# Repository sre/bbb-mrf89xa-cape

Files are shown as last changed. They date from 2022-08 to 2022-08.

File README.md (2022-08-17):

# Beaglebone Black Cape for MRF89XA RF Chip

This is a cape for the MRF89XA RF chip using the 868 MHz ISM band.
It has an onboard antenna, which is good enough for short range
communication. Otherwise and SMA connector can be used to connect
an external amplifier/antenna.

The MRF89XA is connected to the Beaglebone SPI interface and the
relevant control lines are connected to GPIOs. Additionally the
cape has support to drive a SK6812 or WS2812 LED via SPI.

## Image

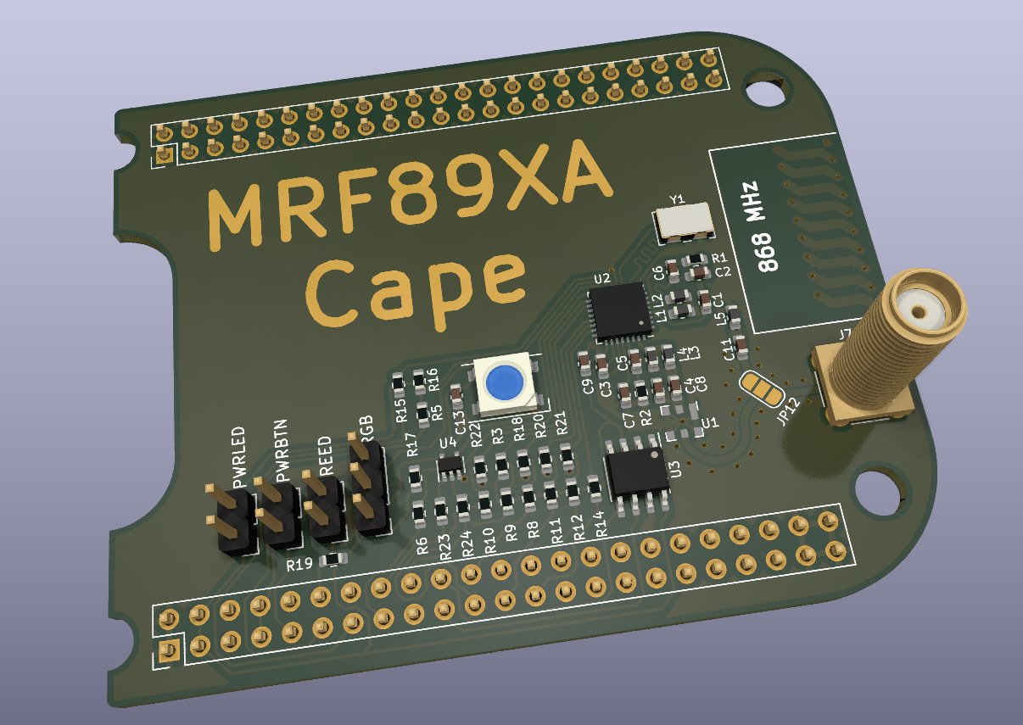
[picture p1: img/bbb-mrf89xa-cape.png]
Rendering from PCB


## Kernel

A matching devicetree overlay can be found in the dt-overlay
directory. Neither the MRF89XA nor the RGB LED currently have
an in-kernel driver. It is possible to access them via userspace
via the spidev module like this:

```
# load spidev kernel module
modprobe spidev
# tell kernel to use spidev driver for both mrf89xa interfaces
echo spidev > /sys/bus/spi/devices/spi0.0/driver_override
echo spi0.0 > /sys/bus/spi/drivers/spidev/bind
echo spidev > /sys/bus/spi/devices/spi0.1/driver_override
echo spi0.1 > /sys/bus/spi/drivers/spidev/bind
echo spidev > /sys/bus/spi/devices/spi0.2/driver_override
echo spi0.2 > /sys/bus/spi/drivers/spidev/bind

```
Afterwards the SPI devices are available as `/dev/spidev0.0`
(mrf89xa data), `/dev/spidev0.1` (mrf89xa cfg) and `/dev/spidev0.2`
(RGB led).

## License

https://creativecommons.org/licenses/by-sa/4.0/

CC-BY-SA 2022 Sebastian Reichel <sre@mainframe.io>

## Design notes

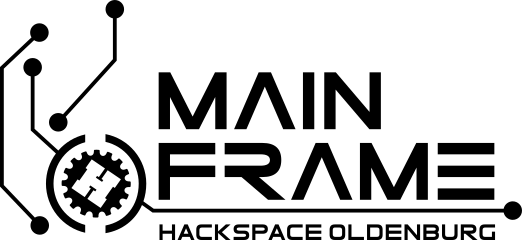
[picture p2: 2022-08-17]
img/mainframe.png

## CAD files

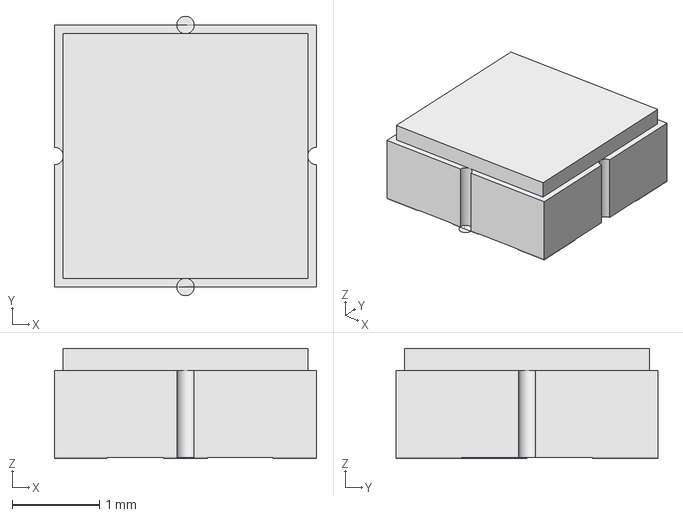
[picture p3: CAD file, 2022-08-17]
3dmodels/DCC6C.step
3.00 x 3.20 x 1.26 mm

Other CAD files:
3dmodels/DCC6C.FCStd

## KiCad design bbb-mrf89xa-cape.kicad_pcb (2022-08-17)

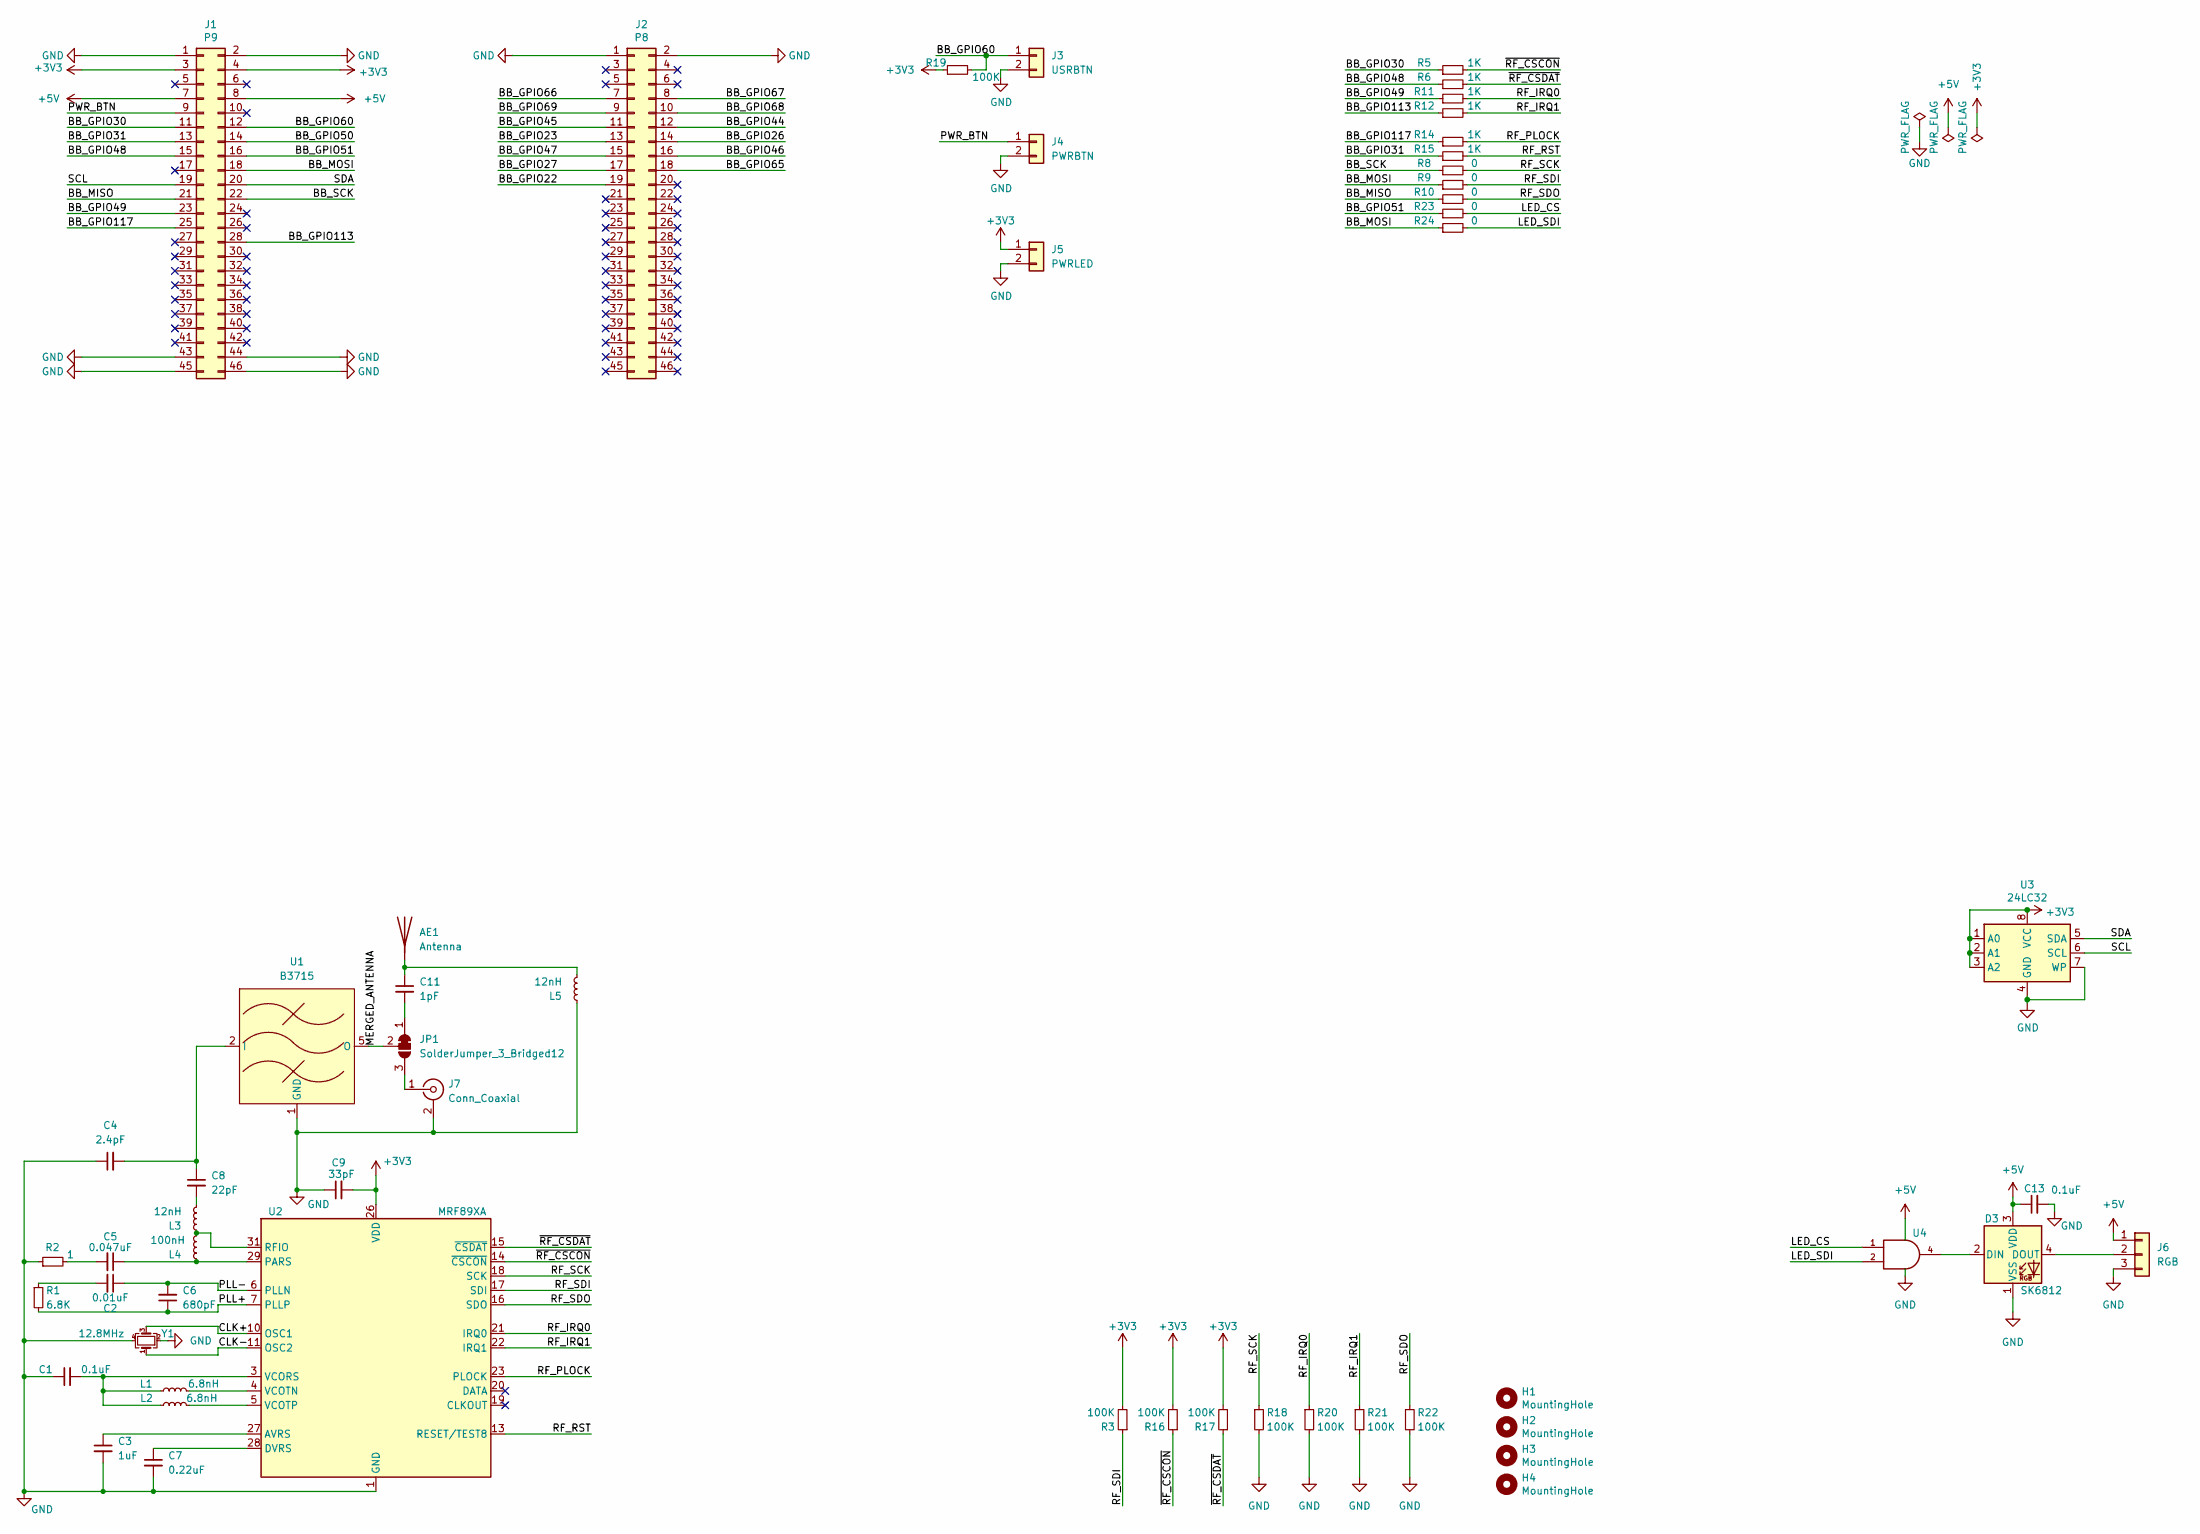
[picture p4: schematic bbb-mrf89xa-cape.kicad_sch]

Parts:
AE1: Antenna; Texas_SWRA416_868MHz_915MHz
C1, C13: 0.1uF; C_0603_1608Metric
C2: 0.01uF; C_0603_1608Metric
C3: 1uF; C_0603_1608Metric
C4: 2.4pF; C_0603_1608Metric
C5: 0.047uF; C_0603_1608Metric
C6: 680pF; C_0603_1608Metric
C7: 0.22uF; C_0603_1608Metric
C8: 22pF; C_0603_1608Metric
C9: 33pF; C_0603_1608Metric
C11: 1pF; C_0603_1608Metric
D3: SK6812; LED_SK6812_PLCC4_5.0x5.0mm_P3.2mm
H1, H2, H3, H4: MountingHole; MountingHole_4.3mm_M4
J1: P9; PinHeader_2x23_P2.54mm_Vertical
J2: P8; PinHeader_2x23_P2.54mm_Vertical
J3: USRBTN; PinHeader_1x02_P2.54mm_Vertical
J4: PWRBTN; PinHeader_1x02_P2.54mm_Vertical
J5: PWRLED; PinHeader_1x02_P2.54mm_Vertical
J6: RGB; PinHeader_1x03_P2.54mm_Vertical
J7: Conn_Coaxial; SMA_Amphenol_132291_Vertical
JP1: SolderJumper_3_Bridged12; SolderJumper-3_P1.3mm_Bridged12_RoundedPad1.0x1.5mm_NumberL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
L1, L2: 6.8nH; L_0603_1608Metric
L3, L5: 12nH; L_0603_1608Metric
L4: 100nH; L_0603_1608Metric
R1: 6.8K; R_0603_1608Metric
R2: 1; R_0603_1608Metric
R3, R16, R17, R18, R19, R20, R21, R22: 100K; R_0603_1608Metric
R5, R6, R11, R12, R14, R15: 1K; R_0603_1608Metric
R8, R9, R10, R23, R24: 0; R_0603_1608Metric
U1: B3715; DCC6C_3x3mm
U2: MRF89XA; QFN-32-1EP_5x5mm_P0.5mm_EP3.1x3.1mm
U3: 24LC32; SOIC-8_3.9x4.9mm_P1.27mm
U4: (no value)
Y1: 12.8MHz; Oscillator_SMD_EuroQuartz_XO53-4Pin_5.0x3.2mm

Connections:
+3V3: C9.2, J1.3, J1.4, J5.1, R3.2, R16.2, R17.2, R19.1, U2.26 (VDD), U3.1 (A0), U3.2 (A1), U3.3 (A2), U3.8 (VCC)
+5V: C13.1, D3.3 (VDD), J1.7, J1.8, J6.1, U4.5 (VCC)
/BB_GPIO22: J2.19
/BB_GPIO23: J2.13
/BB_GPIO26: J2.14
/BB_GPIO27: J2.17
/BB_GPIO30: J1.11, R5.1
/BB_GPIO31: J1.13, R15.1
/BB_GPIO44: J2.12
/BB_GPIO45: J2.11
/BB_GPIO46: J2.16
/BB_GPIO47: J2.15
/BB_GPIO48: J1.15, R6.1
/BB_GPIO49: J1.23, R11.1
/BB_GPIO50: J1.14
/BB_GPIO51: J1.16, R23.1
/BB_GPIO60: J1.12, J3.1, R19.2
/BB_GPIO65: J2.18
/BB_GPIO66: J2.7
/BB_GPIO67: J2.8
/BB_GPIO68: J2.10
/BB_GPIO69: J2.9
/BB_GPIO113: J1.28, R12.1
/BB_GPIO117: J1.25, R14.1
/BB_MISO: J1.21, R10.1
/BB_MOSI: J1.18, R9.1, R24.1
/BB_SCK: J1.22, R8.1
/CLK+: U2.10 (OSC1), Y1.3
/CLK-: U2.11 (OSC2), Y1.1
/LED_CS: R23.2, U4.1
/LED_SDI: R24.2, U4.2
/MERGED_ANTENNA: JP1.2 (C), U1.5 (O)
/PLL+: C6.1, R1.2, U2.7 (PLLP)
/PLL-: C2.1, C6.2, U2.6 (PLLN)
/PWR_BTN: J1.9, J4.1
/RF_IRQ0: R11.2, R20.1, U2.21 (IRQ0)
/RF_IRQ1: R12.2, R21.1, U2.22 (IRQ1)
/RF_PLOCK: R14.2, U2.23 (PLOCK)
/RF_RST: R15.2, U2.13 (RESET/TEST8)
/RF_SCK: R8.2, R18.1, U2.18 (SCK)
/RF_SDI: R3.1, R9.2, U2.17 (SDI)
/RF_SDO: R10.2, R22.1, U2.16 (SDO)
/SCL: J1.19, U3.6 (SCL)
/SDA: J1.20, U3.5 (SDA)
/~RF_CSCON: R5.2, R16.1, U2.14 (~CSCON)
/~RF_CSDAT: R6.2, R17.1, U2.15 (~CSDAT)
GND: C1.1, C3.2, C4.1, C7.2, C9.1, C13.2, D3.1 (VSS), J1.1, J1.2, J1.43, J1.44, J1.45, J1.46, J2.1, J2.2, J3.2, J4.2, J5.2, J6.3, J7.2 (Ext), L5.1, R2.1, R18.2, R20.2, R21.2, R22.2, U1.1 (GND), U1.3 (GND), U1.4 (GND), U1.6 (GND), U2.1 (GND), U2.2 (GND), U2.8 (GND), U2.9 (GND), U2.12 (GND), U2.24 (GND), U2.25 (GND), U2.30 (GND), U2.32 (GND), U2.33 (GND), U3.4 (GND), U3.7 (WP), U4.3 (GND), Y1.2, Y1.4
unnamed: AE1.1 (A), C11.1, L5.2
unnamed: C1.2, L1.1, L2.1, U2.3 (VCORS)
unnamed: C2.2, R1.1
unnamed: C3.1, U2.27 (AVRS)
unnamed: C4.2, C8.1, U1.2 (I)
unnamed: C5.1, L4.1, U2.29 (PARS)
unnamed: C5.2, R2.2
unnamed: C7.1, U2.28 (DVRS)
unnamed: C8.2, L3.2
unnamed: C11.2, JP1.1 (A)
unnamed: D3.2 (DIN), U4.4
unnamed: D3.4 (DOUT), J6.2
unnamed: J7.1 (In), JP1.3 (B)
unnamed: L1.2, U2.4 (VCOTN)
unnamed: L2.2, U2.5 (VCOTP)
unnamed: L3.1, L4.2, U2.31 (RFIO)

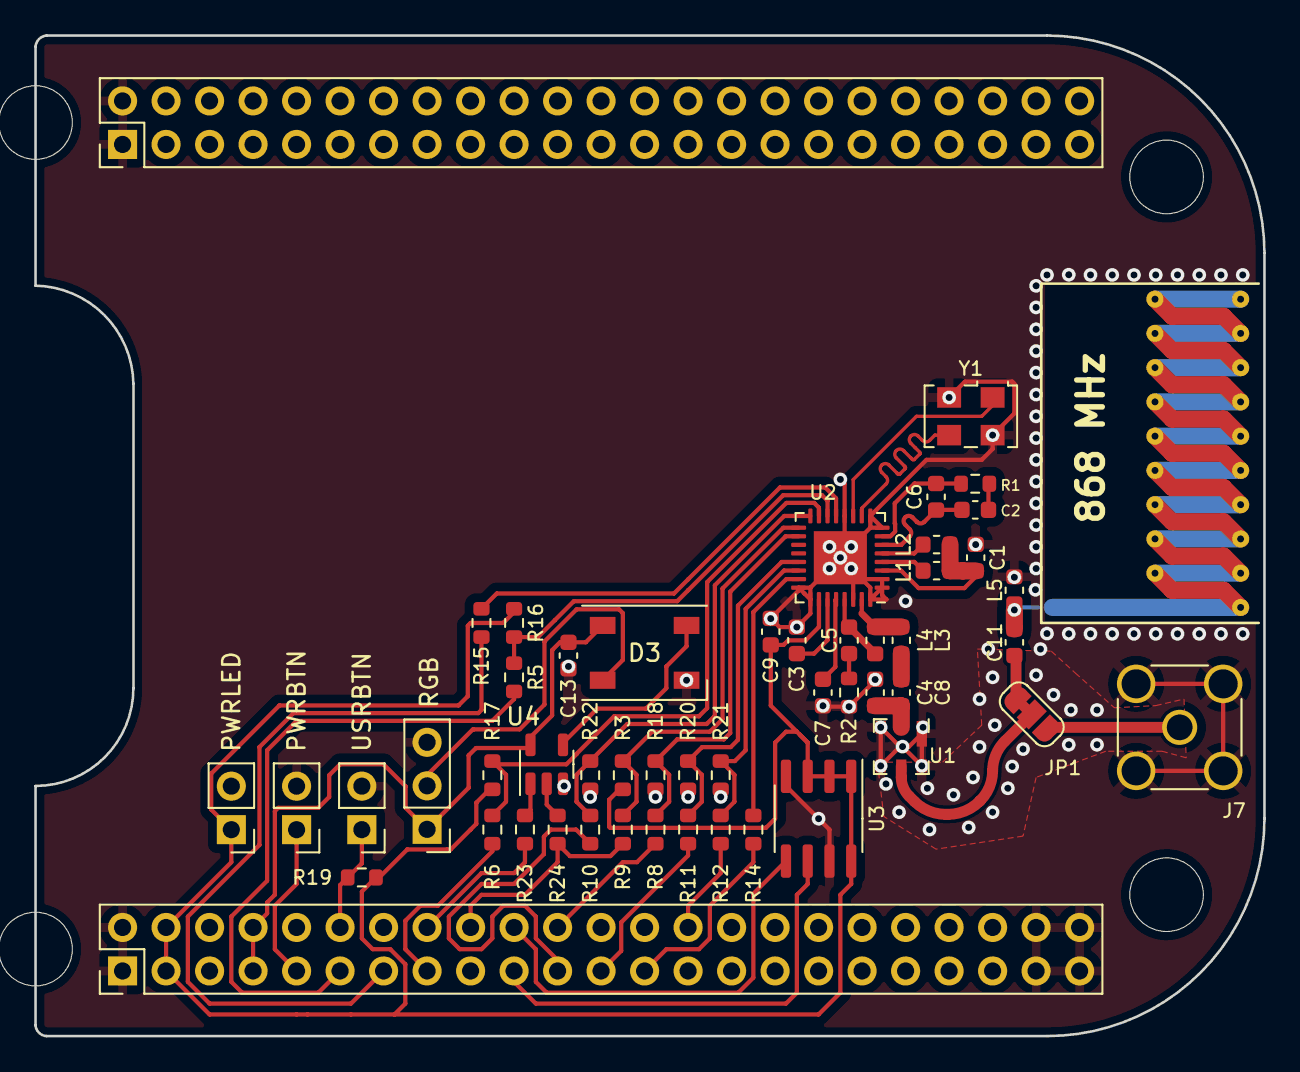
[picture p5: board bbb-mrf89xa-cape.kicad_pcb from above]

Board: 2 copper layers, 71.8 x 58.4 mm, 56 parts (1 on the bottom side), 49 nets.

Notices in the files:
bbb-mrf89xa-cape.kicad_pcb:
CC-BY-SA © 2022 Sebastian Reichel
